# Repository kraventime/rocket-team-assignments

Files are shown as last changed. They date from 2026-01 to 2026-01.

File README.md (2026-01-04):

PCB Design Assignments given by IITB Rocket Team - Avionics Subsystem:
# BMI160 IMU Breakout Board
Design a 2-layer breakout board for the Bosch BMI160 6-axis IMU (QFN-24 package).
# Basic Flight Computer with Sensors
Design a PCB which can record and store data onboard incorporating:
1. RP2040 MCU + W25Q128J flash with SOT package and XIP support + 12 MHz crystal oscillator (10-20 PPM tolerance)
2. USB-C port (try to do 90 ohm impedance matching for the differential pairs)
3. BMP280 barometric pressure sensor + BMI160 IMU + KX134 high range accelerometer
4. Voltage regulators for battery and USB

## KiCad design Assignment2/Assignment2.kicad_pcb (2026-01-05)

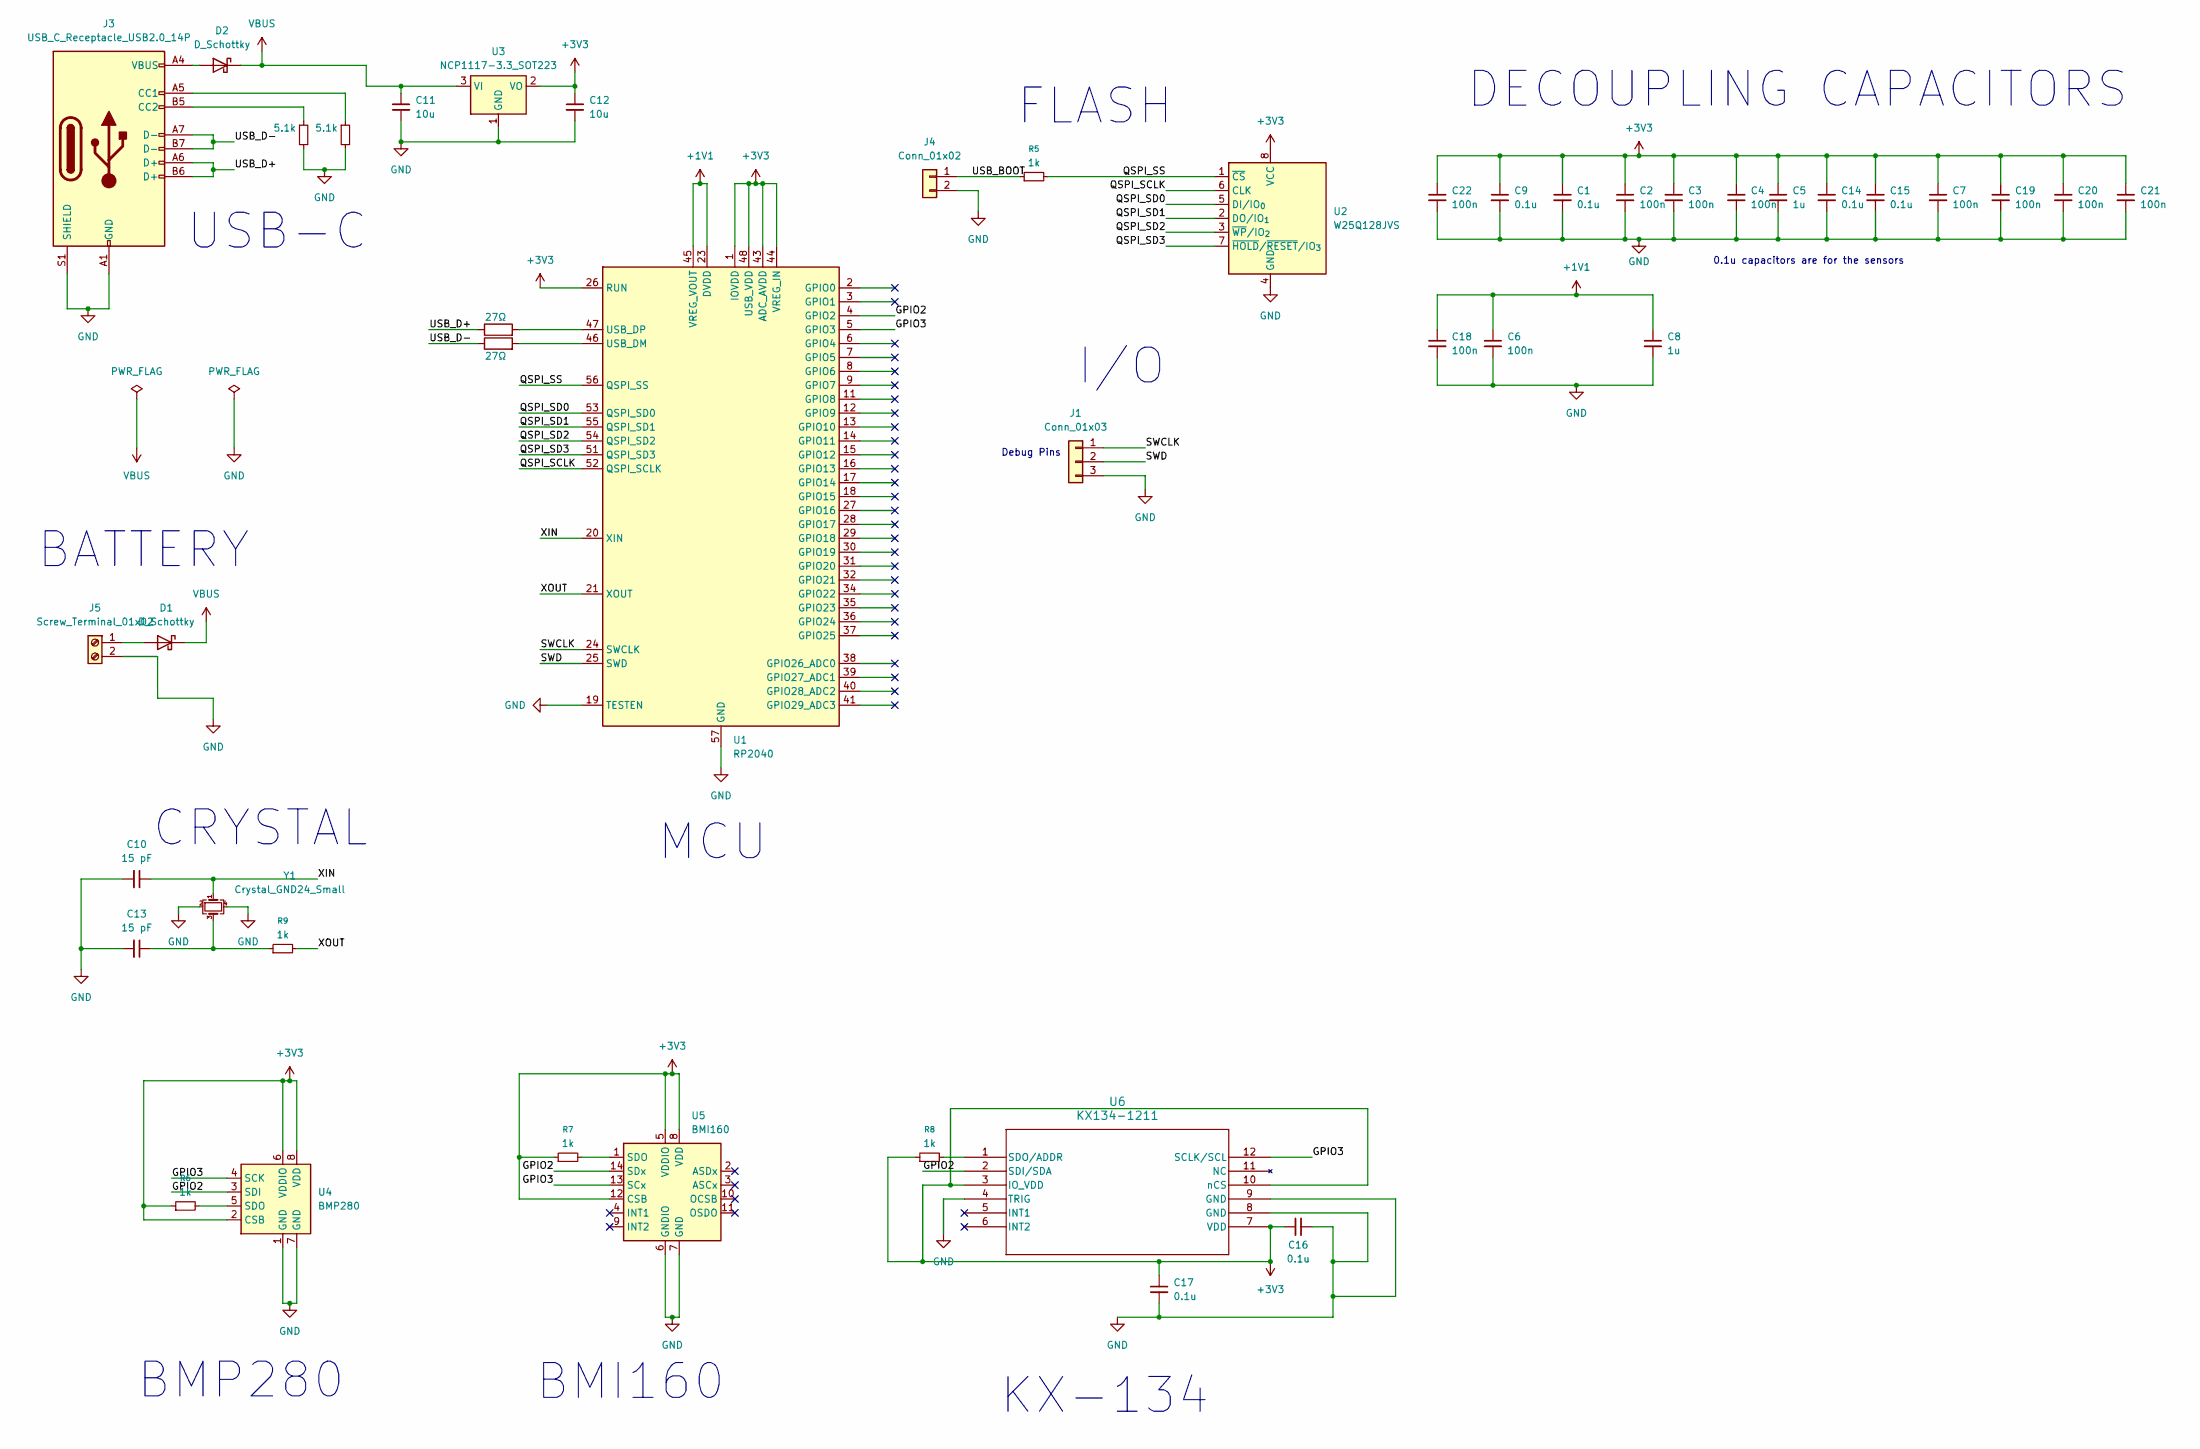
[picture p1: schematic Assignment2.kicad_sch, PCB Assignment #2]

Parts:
C1, C9, C14, C15, C16, C17: 0.1u; C_0201_0603Metric
C2, C3, C4, C6, C7, C18, C19, C20, C21, C22: 100n; C_0201_0603Metric
C5, C8: 1u; C_0201_0603Metric
C10, C13: 15 pF; C_0201_0603Metric
C11, C12: 10u; C_0201_0603Metric
D1, D2: D_Schottky; D_2114_3652Metric
J1: Conn_01x03; PinHeader_1x03_P2.54mm_Vertical
J3: USB_C_Receptacle_USB2.0_14P; USB_C_Receptacle_JAE_DX07S016JA1R1500
J4: Conn_01x02; PinHeader_1x02_P2.54mm_Vertical
J5: Screw_Terminal_01x02; TerminalBlock_Phoenix_MPT-0,5-2-2.54_1x02_P2.54mm_Horizontal
R1, R2: 27Ω; R_0201_0603Metric
R3, R4: 5.1k; R_0201_0603Metric
R5, R6, R7, R8, R9: 1k; R_0201_0603Metric
U1: RP2040; QFN-56-1EP_7x7mm_P0.4mm_EP3.2x3.2mm
U2: W25Q128JVS; SOIC-8_5.3x5.3mm_P1.27mm
U3: NCP1117-3.3_SOT223; SOT-223-3_TabPin2
U4: BMP280; Bosch_LGA-8_2x2.5mm_P0.65mm_ClockwisePinNumbering
U5: BMI160; Bosch_LGA-14_3x2.5mm_P0.5mm
U6: KX134-1211; LGA12_2X2X0P9_ROM
Y1: Crystal_GND24_Small; Crystal_SMD_Abracon_ABM10-4Pin_2.5x2.0mm

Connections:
+1V1: C6.1, C8.1, C18.1, U1.23 (DVDD), U1.45 (VREG_VOUT), U1.50 (DVDD)
+3V3: C1.1, C2.1, C3.1, C4.1, C5.1, C7.1, C9.1, C12.1, C14.1, C15.1, C16.1, C17.1, C19.1, C20.1, C21.1, C22.1, R6.1, R7.1, R8.1, U1.1 (IOVDD), U1.10 (IOVDD), U1.22 (IOVDD), U1.26 (RUN), U1.33 (IOVDD), U1.42 (IOVDD), U1.43 (ADC_AVDD), U1.44 (VREG_IN), U1.48 (USB_VDD), U1.49 (IOVDD), U2.8 (VCC), U3.2 (VO), U4.2 (CSB), U4.6 (VDDIO), U4.8 (VDD), U5.5 (VDDIO), U5.8 (VDD), U5.12 (CSB), U6.3 (IO_VDD), U6.7 (VDD), U6.10 (nCS)
/GPIO2: U1.4 (GPIO2), U4.3 (SDI), U5.14 (SDx), U6.2 (SDI/SDA)
/GPIO3: U1.5 (GPIO3), U4.4 (SCK), U5.13 (SCx), U6.12 (SCLK/SCL)
/QSPI_SCLK: U1.52 (QSPI_SCLK), U2.6 (CLK)
/QSPI_SD0: U1.53 (QSPI_SD0), U2.5 (DI/IO_{0})
/QSPI_SD1: U1.55 (QSPI_SD1), U2.2 (DO/IO_{1})
/QSPI_SD2: U1.54 (QSPI_SD2), U2.3 (~WP/IO_{2})
/QSPI_SD3: U1.51 (QSPI_SD3), U2.7 (~HOLD/~RESET/IO_{3})
/QSPI_SS: R5.2, U1.56 (QSPI_SS), U2.1 (~CS)
/SWCLK: J1.1, U1.24 (SWCLK)
/SWD: J1.2, U1.25 (SWD)
/USB_BOOT: J4.1, R5.1
/USB_D+: J3.A6 (D+), J3.B6 (D+), R2.1
/USB_D-: J3.A7 (D-), J3.B7 (D-), R1.1
/XIN: C10.1, U1.20 (XIN), Y1.1
/XOUT: R9.2, U1.21 (XOUT)
GND: C1.2, C2.2, C3.2, C4.2, C5.2, C6.2, C7.2, C8.2, C9.2, C10.2, C11.2, C12.2, C13.2, C14.2, C15.2, C16.2, C17.2, C18.2, C19.2, C20.2, C21.2, C22.2, J1.3, J3.A1 (GND), J3.A12 (GND), J3.B1 (GND), J3.B12 (GND), J3.S1 (SHIELD), J4.2, J5.2, R3.2, R4.2, U1.19 (TESTEN), U1.57 (GND), U2.4 (GND), U3.1 (GND), U4.1 (GND), U4.7 (GND), U5.6 (GNDIO), U5.7 (GND), U6.4 (TRIG), U6.8 (GND), U6.9 (GND), Y1.2, Y1.4
unnamed: C13.1, R9.1, Y1.3
unnamed: D1.2 (A), J5.1
unnamed: D2.2 (A), J3.A4 (VBUS), J3.A9 (VBUS), J3.B4 (VBUS), J3.B9 (VBUS)
unnamed: J3.A5 (CC1), R4.1
unnamed: J3.B5 (CC2), R3.1
unnamed: R1.2, U1.46 (USB_DM)
unnamed: R2.2, U1.47 (USB_DP)
unnamed: R6.2, U4.5 (SDO)
unnamed: R7.2, U5.1 (SDO)
unnamed: R8.2, U6.1 (SDO/ADDR)
VBUS: C11.1, D1.1 (K), D2.1 (K), U3.3 (VI)

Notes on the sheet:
I/O
CRYSTAL
BMP280
MCU
DECOUPLING CAPACITORS
Debug Pins
BMI160
KX-134
FLASH
BATTERY
USB-C
0.1u capacitors are for the sensors

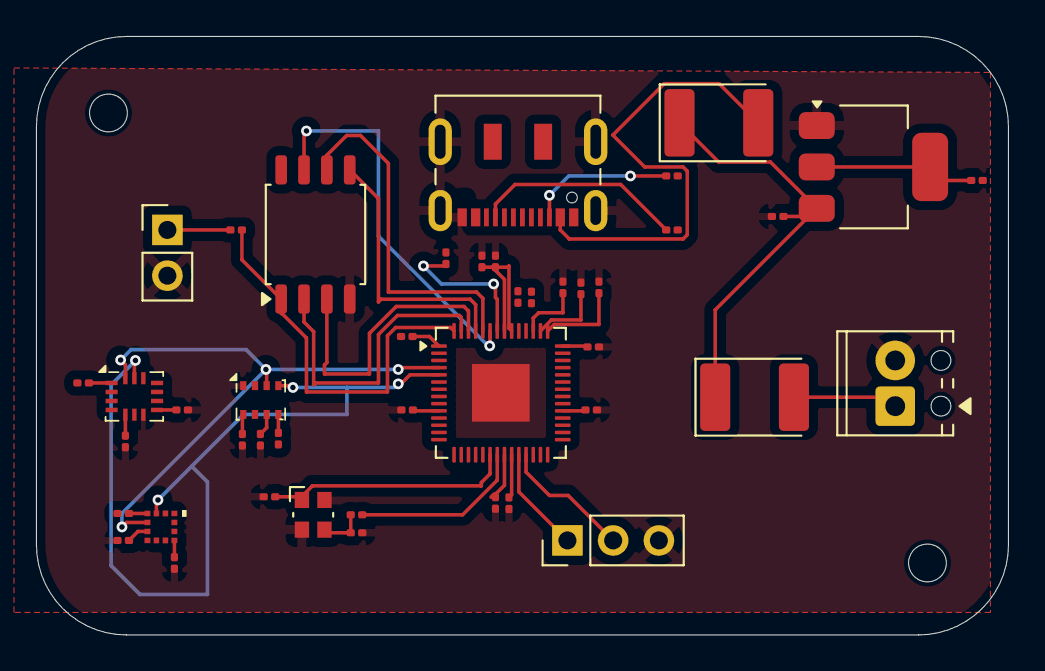
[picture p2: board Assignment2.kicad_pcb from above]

Board: 2 copper layers, 54.0 x 33.2 mm, 44 parts (0 on the bottom side), 29 nets.

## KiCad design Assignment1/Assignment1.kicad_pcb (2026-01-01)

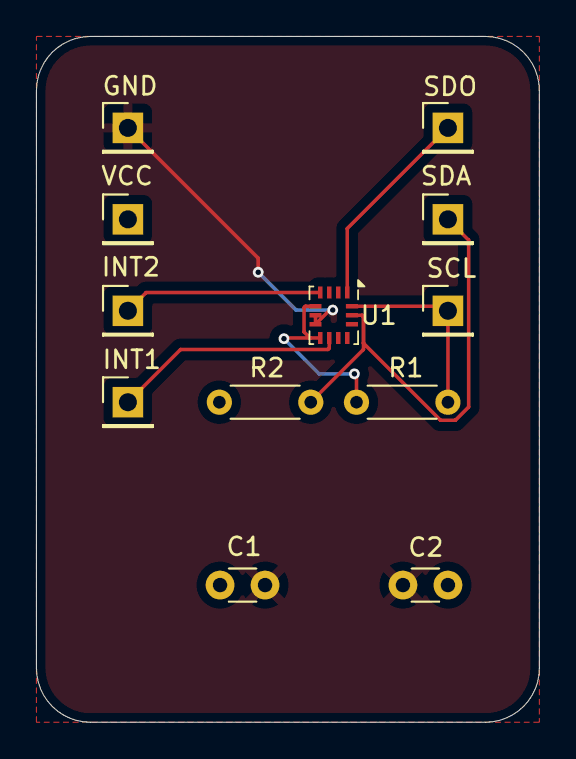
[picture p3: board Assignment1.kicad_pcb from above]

Board: 2 copper layers, 27.9 x 38.1 mm, 12 parts (0 on the bottom side), 7 nets.

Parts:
C1, C2: 100nF; C_Disc_D3.0mm_W1.6mm_P2.50mm
GND: Conn_01x01_Pin; PinHeader_1x01_P2.54mm_Vertical
INT1: INT1; PinHeader_1x01_P2.54mm_Vertical
INT2: INT2; PinHeader_1x01_P2.54mm_Vertical
R1, R2: R_Small_US; R_Axial_DIN0204_L3.6mm_D1.6mm_P5.08mm_Horizontal
SCL: SCL; PinHeader_1x01_P2.54mm_Vertical
SDA: SDA; PinHeader_1x01_P2.54mm_Vertical
SDO: SDO; PinHeader_1x01_P2.54mm_Vertical
U1: BMI160; Bosch_LGA-14_3x2.5mm_P0.5mm
VCC: Conn_01x01_Pin; PinHeader_1x01_P2.54mm_Vertical

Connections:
GND: C1.2, C2.1, GND.1, U1.6 (GNDIO), U1.7 (GND)
unnamed: INT1.1, U1.4 (INT1)
unnamed: INT2.1, U1.9 (INT2)
unnamed: R2.2, SCL.1, U1.13 (SCx)
unnamed: SDO.1, U1.1 (SDO)
unnamed: R1.2, SDA.1, U1.14 (SDx)
VCC: C1.1, C2.2, R1.1, R2.1, U1.5 (VDDIO), U1.8 (VDD), VCC.1

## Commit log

2026-01-01 Design a breakout board for the BMI-160 IMU
    [Assignment1-B_Cu.gbr, Assignment1-B_Mask.gbr, Assignment1-B_Silkscreen.gbr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]
2026-01-02 Design Schematic for Assignment 2
    [Assignment2.kicad_pcb, Assignment2.kicad_sch]
2026-01-03 Make changes to schematic
    [Assignment2.kicad_sch]
2026-01-03 Revise Schematic. Set PCB Constraints
    [Assignment2.kicad_pcb, Assignment2.kicad_sch]
2026-01-04 Arrange PCB elements systematically. Drawing traces still left.
    [Assignment2.kicad_pcb, Assignment2.kicad_sch]
2026-01-05 Join traces. USB Differential Pair still left.
    [Assignment2.kicad_pcb, Assignment2.kicad_sch]
